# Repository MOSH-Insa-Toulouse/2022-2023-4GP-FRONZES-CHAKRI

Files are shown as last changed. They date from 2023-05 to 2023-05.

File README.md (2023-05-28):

# 2022-2023-4GP-FRONZES-CHAKRI
## General description

During the UF “Du capteur au banc de test” (“From sensor to test bench”), a 4th year course in the Physics Engineering Department at INSA Toulouse, we produced a graphite-based strain gauge that is low-tech, low-cost and transportable. We measure its resistance to determine its deformation. Data is transmitted to an Android application via an analogue circuit and a microcontroller. We used an Arduino Uno board, a PCB, a Bluetooth module, an OLED screen, a flex sensor and designed the application using MIT App Inventor. 

## Table of contents
* [Graphite sensor conception](#concep)
* [Deliverables](#deliv)
* [Components](#comp)
* [LTSpice](#spice)
* [PCB Shield](#pcb)
* [Application](#app)
* [Arduino](#ard)
* [Test bench](#bench)
* [Datasheet](#data)
* [Improvements](#improv)

<div id='concep'/>

## Graphite sensor conception

We printed the sensor outline on a piece of paper, and then filled the "U" shepe with a pencil. We can add more or less graphite by pressing the pencil with more or less strength. The HB scale, which indicates the proportion of graphite in a pencil, goes from 9B (lower proportion of graphite) to 9H (higher proportion of graphite). When we apply a tensile stress, the molecules move away from each other and the resistance increases. On the other hand, when they are compressed, they bond together and the resistance decreases.

<div id='deliv'/>

## Deliverables

The deliverables of this project are the following:

* An example of the analogue circuit to which the sensor can be connected, produced using LTSpice software
* A PCB Shield
* An Arduino code to transmit the measurements made by the sensor to an OLED screen and a Bluetooth module, connected to an Android system
* An APK application
* A test bench
* A datasheet

<div id='comp'/>

## Components

The components required to build the analogue circuit are listed below:

* Arduino Uno
* LTC1050 amplifier
* HC05 Bluetooth module
* 128x64 OLED screen
* GT055 rotary encoder
* Paper sensor
* Resistors: 1 of 1 kΩ, 1 of 10 kΩ, 1 of 39 kΩ, 2 of 100 kΩ
* Capacitors: 2 of 100 nF, 1 of 1 F

<div id='spice'/>

## LTSpice

We used the LTSpice software to simulate the analogue circuit in which our sensor is integrated.

The strain sensor is passive and needs a conditionner. The measured resistance is around 20 to 100 MΩ. We apply a 5 V voltage, so the output signal of the sensor is very low, around a 100 nA. We have to filter and amplify it.

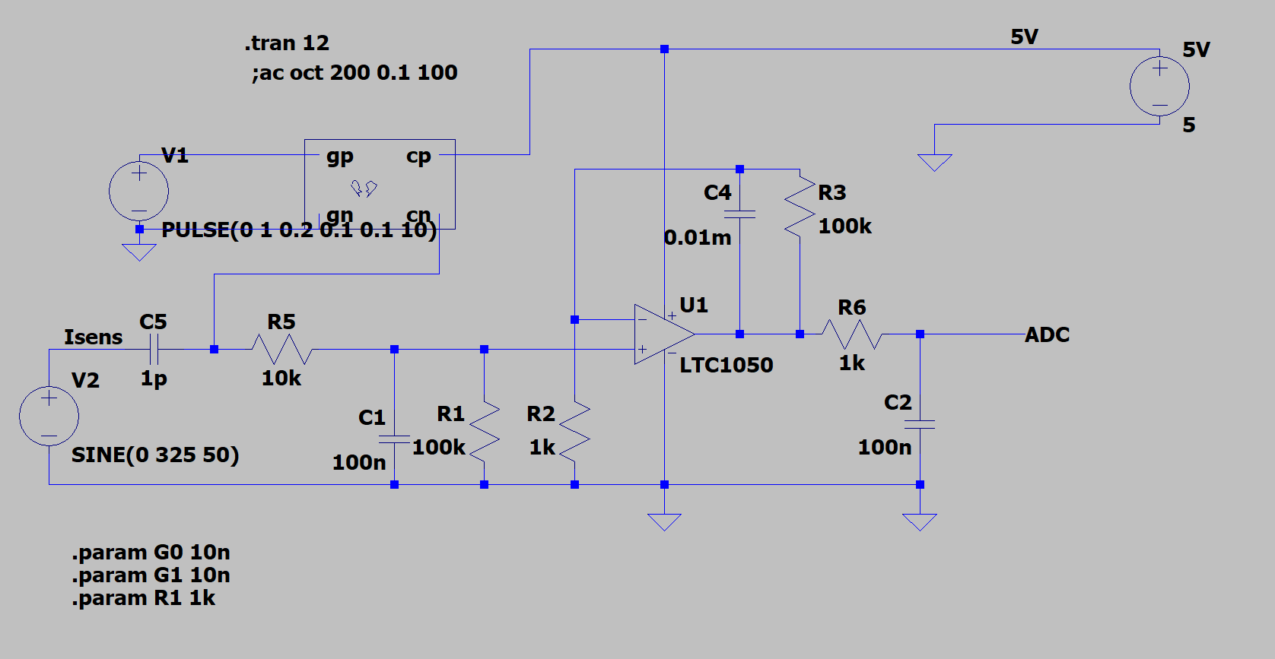
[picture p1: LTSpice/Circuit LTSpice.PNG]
spice


Use of a LTC1050 amplifier:

> Low input current

> Low offset tension

> Insensitivity to common mode

Role of the different components:

> R5 protects the amplifier against electrostatic discharges, and makes a filter for voltage noise with C1

> C1 and R1 make a filter for current noise

> R2 is replaceable: by using the digital potentiometer instead, we can modify the gain of the system

> C4 and R3 make an active filter

> C2 and R6 make a passive output filter

We calculated the value of the sensor resistance based on all the components of the circuit: 𝑹_𝒔𝒆𝒏𝒔=(𝟏+𝑹_𝟑/𝑹_𝟐 )(𝑽_𝒄𝒄/𝑽_𝒂𝒅𝒄 )−𝑹_𝟏−𝑹_𝟓

The circuit can be found in the [LTSpice](https://github.com/MOSH-Insa-Toulouse/2022-2023-4GP-FRONZES-CHAKRI/tree/main/LTSpice) folder.

<div id='pcb'/>

## PCB Schield

To design the PCB, we drew the electronic schematic and its components with KiCad, in a Schematic file. We had to connect the pins of the components to those of the Arduino and to choose their footprints.

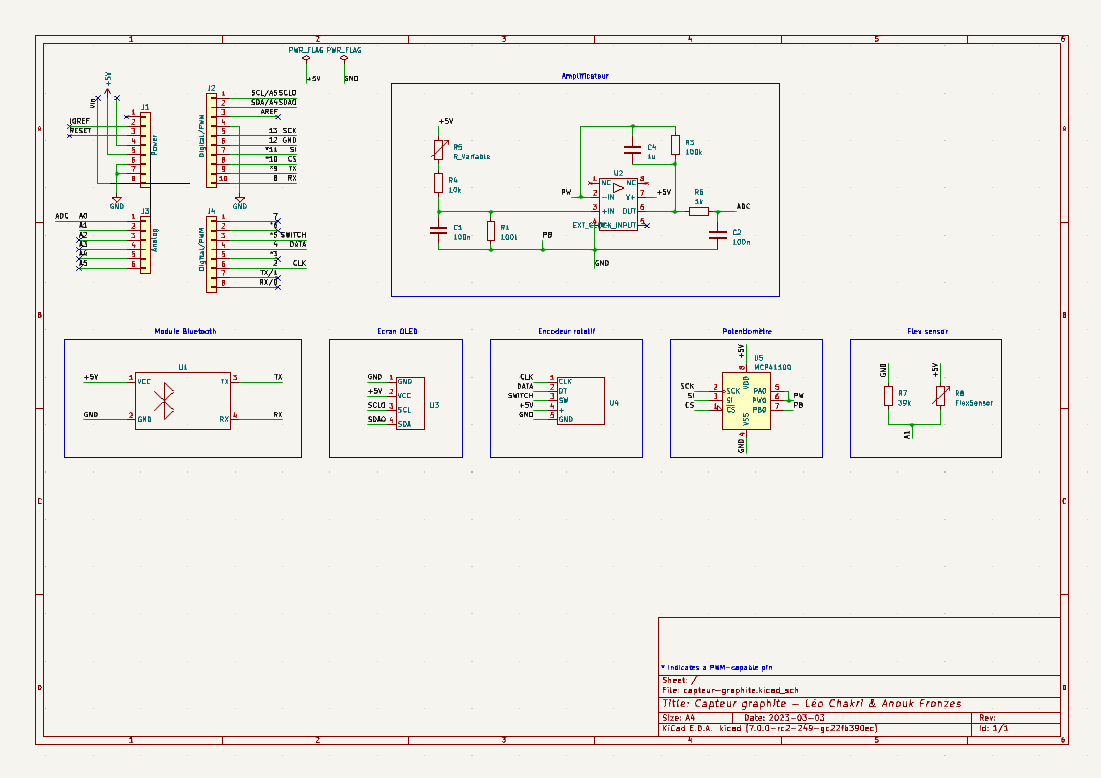
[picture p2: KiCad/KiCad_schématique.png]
schematic


Secondly, we placed the components on the PCB so that they did not overlap, making sure that the tracks and pins were the right width.

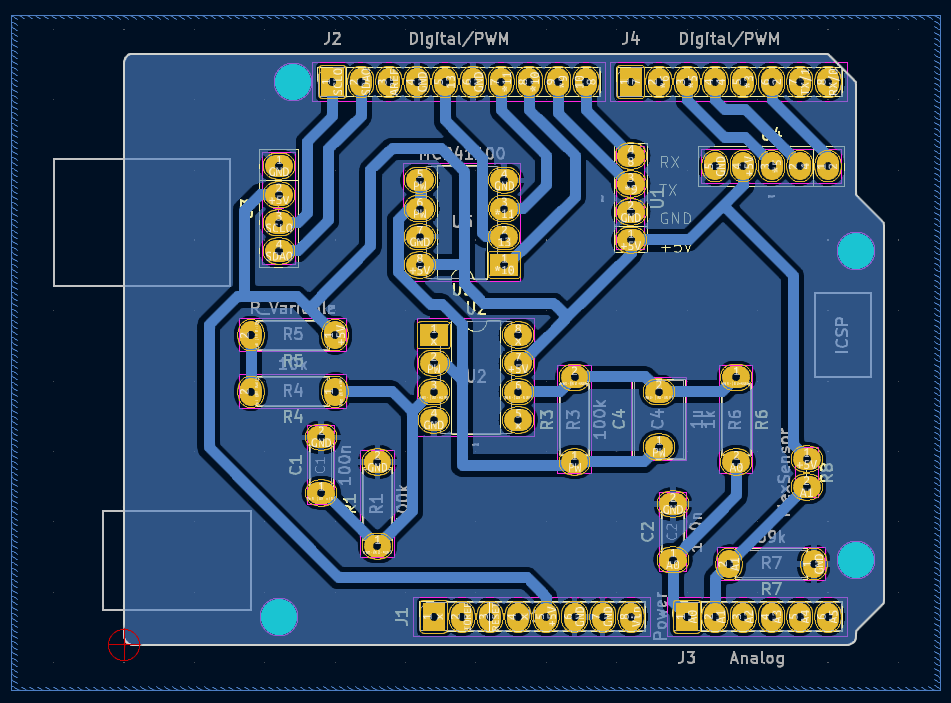
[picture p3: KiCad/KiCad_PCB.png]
pcb


Thirdly, Mrs Crouzet helped us print the circuit, with five steps:

> The circuit is printed on a plastic film

> UV insolation: the mask is deposited on a wafer covered with copper and photoresist

> Development to remove the resist

> Etching with an iron perchloride bath

> The remaining resist is eliminated with acetone

Then we drilled the PCB (0.8 mm holes for all the pins, except those of the Arduino which are 1 mm).

The folder containing all the KiCad files is available [here](https://github.com/MOSH-Insa-Toulouse/2022-2023-4GP-FRONZES-CHAKRI/tree/main/KiCad).

<div id='app'/>

## Application

The measurements taken using the graphite sensor are sent via the Bluetooth module to an Android APK application created using MIT App Inventor ([link to website](https://appinventor.mit.edu/)).

This is the screen with the graph, i.e. the front panel:

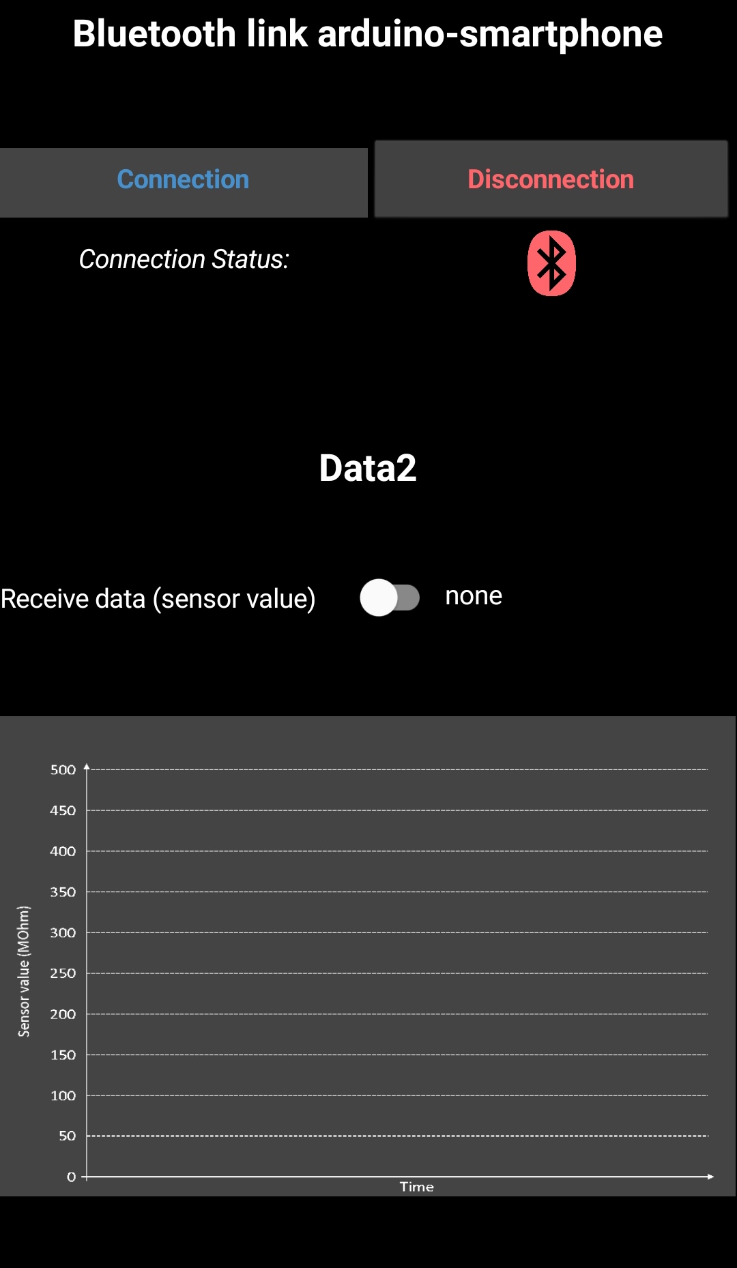
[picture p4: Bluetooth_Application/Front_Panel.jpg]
fpanel


Below is a block diagram of the rear panel:

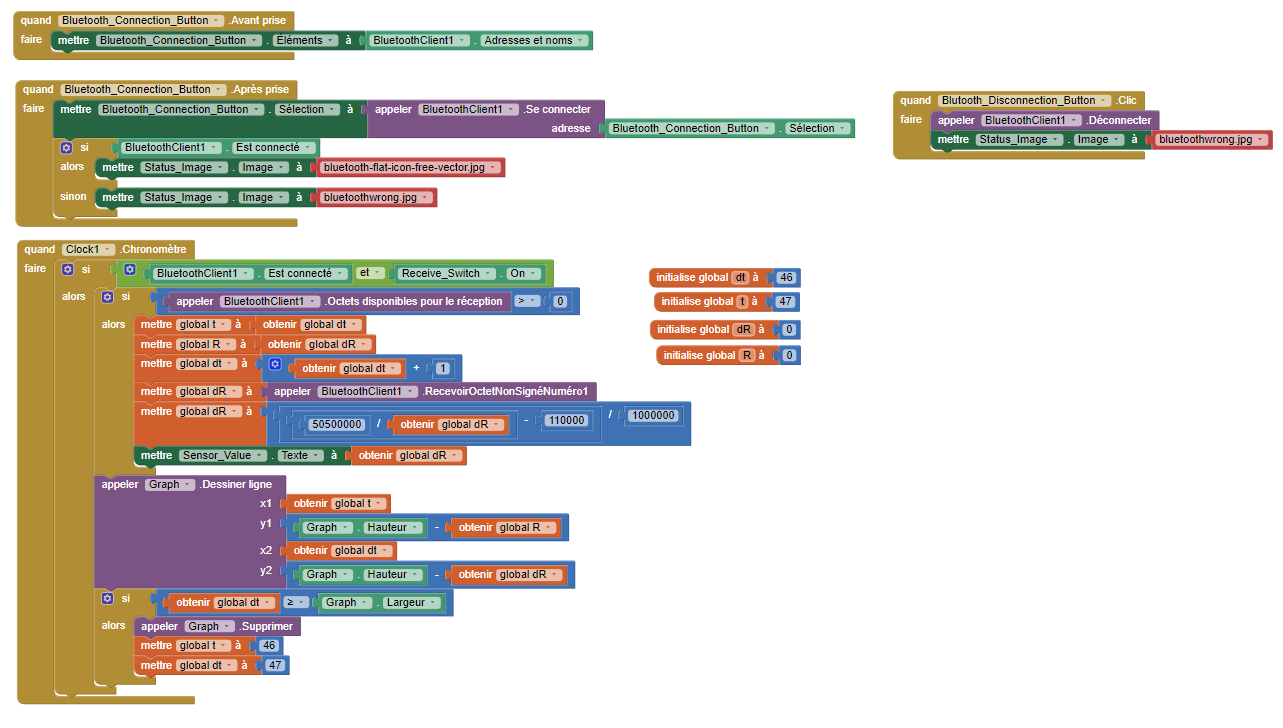
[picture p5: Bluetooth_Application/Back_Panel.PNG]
rpanel


You can find the application code in the [Application](https://github.com/MOSH-Insa-Toulouse/2022-2023-4GP-FRONZES-CHAKRI/tree/main/Bluetooth_Application) folder.

<div id='ard'/>

## Arduino

The entire project is based on the Arduino code, which links all the system's components and functions. The Arduino retrieves and stores the resistance values from the graphite sensor. It displays them on the OLED screen and connects to the Bluetooth module to send the data to the application.

[Here](https://github.com/MOSH-Insa-Toulouse/2022-2023-4GP-FRONZES-CHAKRI/tree/main/Arduino_Program) is the Arduino code.

<div id='bench'/>

## Test bench

To check that the sensor was working properly and to create our datasheet, we used a pre-existing test bench made up of half-spheres of varying radii. The sheet of paper on which the graphite is deposited can be folded along the curve of the half-sphere, in order to measure the change in resistance of the sensor at regular intervals.

The variation curves obtained can be accessed via the [datasheet](https://github.com/MOSH-Insa-Toulouse/2022-2023-4GP-FRONZES-CHAKRI/blob/main/Datasheet/Datasheet.pdf).

<div id='data'/>

## Datasheet

It was established by using the test bench. We measured the variations in resistance depending on the deformation for HB and 2B pencils. For each half-sphere radius, we took five tensile measurements and then calculated their average value. We reproduced the process for compression. It is important to note that the measured resistance depends on the amount of graphite deposited on the paper (and therefore on the intensity with which you press while colouring). But we established the ratio of these average values compared to the resting resistance, so the deformation graphs can be used for any amount of deposited graphite.

The datasheet is available [here](https://github.com/MOSH-Insa-Toulouse/2022-2023-4GP-FRONZES-CHAKRI/blob/main/Datasheet/Datasheet.pdf).

<div id='improv'/>

## Improvements

The pins used to connect the clips of the sheet of paper to the PCB are too close to the OLED screen, which makes the connection a little difficult.

We could have used the digital potentiometer to add a new function, as it already has a slot on the PCB, but we ran out of time to code it.

We could have tested more pencil types to include them in the datasheet, and compared the values we obtained with those of other pairs, to make the datasheet more precise and accurate.

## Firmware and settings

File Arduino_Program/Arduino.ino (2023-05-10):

/*
  File : CapteurGraphite.ino
  Description : Allows calibration, control and data acquisition of the sensor
  Authors : Anouk FRONZES, Léo CHAKRI
  Created on : 12.03.2023
*/



/* *** Libraries and constants *** */

// OLED SCREEN
#include <Adafruit_SSD1306.h>
#define PixelsLenghtOLED 128                                              //OLED screen size, in pixels, at its length
#define PixelsWidthOLED 64                                                //OLED screen size, in pixels, at its width
#define ResetPinOLED -1                                                   //reset of OLED shared with the Arduin 
#define I2CAdressOLED 0x3C                                                //address of the OLED display on the I2C bus (usually 0x3C or 0x3D)
#define CharacterSize 0.8   

Adafruit_SSD1306 OLEDScreen(PixelsLenghtOLED, PixelsWidthOLED, &Wire, ResetPinOLED);

// BLUETOOTH
#include <SoftwareSerial.h>
#define rxPin 9                                                          //Pin 11 as RX, connect to TX of HC-05
#define txPin 8                                                          //Pin 10 as RX, connect to TX of HC-05
#define Clock 50                                                          //Clock for sending data via bluetooth

SoftwareSerial mySerial(rxPin ,txPin);                                    //Definition of software serial
unsigned long t=0;

// SENSOR
float SensorResistance = 0.0;
const int flexPin = A1;
const float VCC = 5;                                                      //voltage at Ardunio 5V line
const float R_DIV = 39000.0;                                              //resistor used to create a voltage divider
const float flatResistance = 24500.0;                                     //resistance when flat
const float bendResistance = 65000.0;                                     //resistance at 90 deg



/* *** Sub-programs *** */

// OLED SCREEN
void DisplayOLED (float SensorResistance, float FlexSensorResistance) {   //display data on the OLED screen

  SensorResistance=SensorResistance/1000000;                              //converts value into Mohms
  FlexSensorResistance=FlexSensorResistance/1000000;                      //converts value into Mohms

  //settings
  OLEDScreen.clearDisplay();
  OLEDScreen.setTextSize(CharacterSize);
  OLEDScreen.setTextColor(SSD1306_WHITE, SSD1306_BLACK);
  OLEDScreen.setCursor(0, 0);
  //data desplay
  OLEDScreen.print("RSens: ");
  OLEDScreen.print(SensorResistance);
  OLEDScreen.println(" MOhm");
  OLEDScreen.println("");
  OLEDScreen.print("Rflex: ");
  OLEDScreen.print(FlexSensorResistance);
  OLEDScreen.println(" MOhm");
  OLEDScreen.display();

}



/* *** SETUP *** */

void setup() {

  OLEDScreen.begin(SSD1306_SWITCHCAPVCC, I2CAdressOLED);                  //OLED initialization

  pinMode(flexPin, INPUT);                                                //pin initialization
  pinMode(rxPin,INPUT);
  pinMode(txPin,OUTPUT);

  Serial.begin(9600);
  mySerial.begin(9600);

}



/* *** LOOP *** */

void loop() {

  int ADCflex = analogRead(flexPin);                                      //reading Arduino's flexpin value (flex sensor)
  float Vflex = ADCflex * VCC / 1023.0;                                   //converts it to voltage
  float Rflex = R_DIV * (VCC / Vflex - 1.0);                              //converts it to sensor resistance

  float sensorValue = analogRead(A0);                                     //reading Arduino's sensorpin value (graphite sensor)
  float SensorResistance = 50500000/sensorValue - 110000;                 //converts it to resistance (parameters depend on the circuit)

  DisplayOLED(SensorResistance,Rflex);                                    //data display on the OLED screen

  Serial.println(SensorResistance);                                       //data display on serial monitor

  if (abs(millis()-t) > Clock){                                
    t=millis();
    byte V = map(sensorValue,0,1023,0,255);                          //converts resistance to byte 
    mySerial.write(V);                                                    //send data to smartphone
  }

  delay(10);

}

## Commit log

2023-05-03 Arduino.ino
    This is the program controlling the entire acquisition chain of our graphite sensor:
    - Measurement and conversion of the circuit voltage
    - Bluetooth device arduino-application
    - Display and management of the OLED screen
2023-05-03 Bluetooth Application
    This is the application to receive the graphite sensor values in real time via Bluetooth.
2023-05-03 Datasheet
    This is the datasheet of our sensor, explaining in detail the use of the graphite sensor, the parameters to be taken into account and the conditions for carrying out the various tests.
